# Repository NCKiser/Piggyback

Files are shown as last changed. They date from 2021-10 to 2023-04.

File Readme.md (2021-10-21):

Piggyback is a small circuit board that carries an Atmega-32u4-MU microprocessor and all of the supporting components needed for it to run. The only thing you need to provide is 5V power and ground.

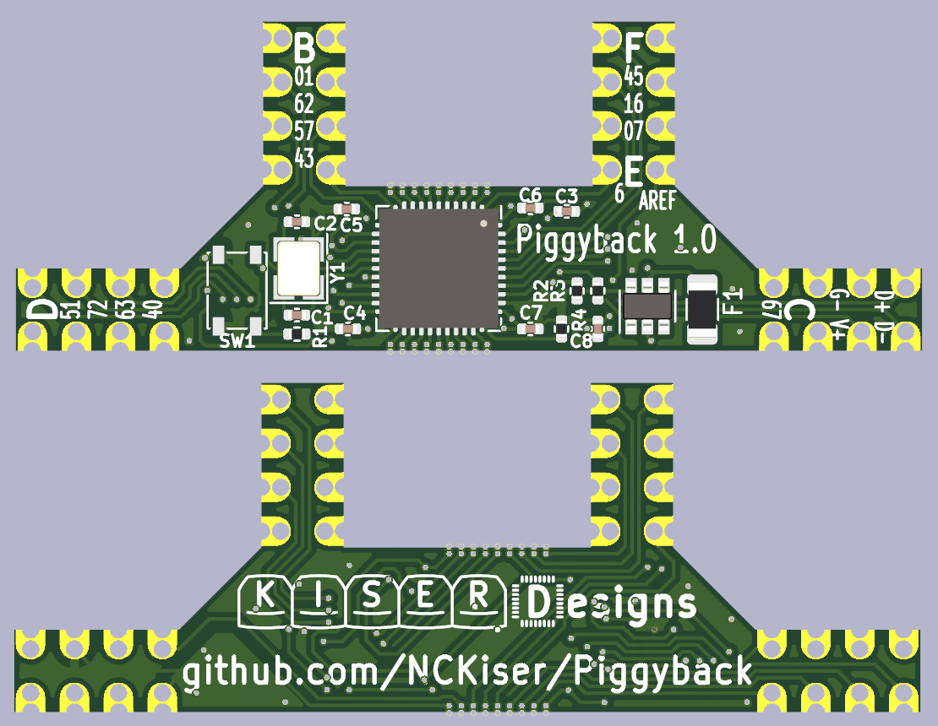
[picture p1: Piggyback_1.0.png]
Piggyback 1.0 Image


Piggyback has 4 legs, each with 8 castellated holes spaced 0.1in (2.54mm) apart. These legs break out all of the GPIO, power, and USB Data pins. Each leg roughly corresponds to a port of the 32u4's IO.

Piggyback was designed with custom mechanical keyboard PCBs in mind. The board fits snuggly under a row of MX or Alps style switches spaced 0.75in (19.05mm) apart. The legs fit within the space between the switch footprints.

Piggyback features ESD protection on the USB data lines, as well as a 500mA resettable polyfuse on the 5V line.

To use the Piggyback in your PCB designs, (load and place the symbol and footprint in your schematic and PCB), and wire it up to your USB port and key matrix. If you are using a USB-C connector, you will need to take care of the CC pins on your own (usually with 5.1k resistors to ground).

This is open-source, as long as you give credit, and is free for commercial use. You can make, modify, and sell this board as you please, as long as you do not claim to own the copyright.

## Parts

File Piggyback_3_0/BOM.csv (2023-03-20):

Designator | Footprint | Quantity | Value | LCSC Part #
C1, C2, C3, C5 | 402 | 4 | 1u | C52923
C10, C11, C12, C16, C7, C8, C9 | 402 | 7 | 100n | C1525
C4 | 402 | 1 | 10u | C15525
D1, D2, D3 | D_SOD-123 | 3 | D_Small | C81598
EZ1 | PicoEZMate-Reinforced-Lite | 1 | 78171-0004 | C2840019
F1 | 1206 | 1 | 500mA | C70076
J1, J5 | PinHeader_1x06_P2.54mm_Vertical | 2 | Conn_01x06_Female
J2 | PinHeader_1x22_P2.54mm_Vertical | 1 | Conn_01x23_Female
J3 | USB_C_Receptacle_HRO_TYPE-C-31-M-12 | 1 | USB_C_Receptacle_USB2.0 | C165948
R1, R2, R3 | 402 | 3 | 5.1k | C25905
R4, R5 | 402 | 2 | 27 | C25092
R6, R8 | 402 | 2 | 1k | C11702
R7 | 402 | 1 | -10k
SW7, SW8, SW9 | SW_MX_1u | 3 | MX_SW_solder
SWR1, SWR2 | SW_Push_SPST_NO_Alps_SKRK | 2 | SW_SPST | C843669
U1 | QFN40P700X700X90-57N | 1 | RP2040TR7 | C2040
U2 | SOT-23 | 1 | XC6206PxxxMR | C5446
U3 | SOT-23-6-routable | 1 | SRV05-4 | C85364
U4 | SOIC-8_5.23x5.23mm_P1.27mm | 1 | W25Q128JVS | C97521
Y2 | Resonator_SMD_Murata_CSTxExxV-3Pin_3.0x1.1mm | 1 | Crystal_GND2_Small | C2659460

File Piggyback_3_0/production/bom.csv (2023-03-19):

Designator | Footprint | Quantity | Value | LCSC Part #
C1, C2, C3, C5 | 0402 | 4 | 1u
C10, C11, C12, C16, C7, C8, C9 | 0402 | 7 | 100n
C4 | 0402 | 1 | 10u
D1, D2, D3 | D_SOD-123 | 3 | D_Small
EZ1 | PicoEZMate-Reinforced-Lite | 1 | 78171-0004
F1 | 1206 | 1 | 500mA
J1, J5 | PinHeader_1x06_P2.54mm_Vertical | 2 | Conn_01x06_Female
J2 | PinHeader_1x22_P2.54mm_Vertical | 1 | Conn_01x23_Female
J3 | USB_C_Receptacle_HRO_TYPE-C-31-M-12 | 1 | USB_C_Receptacle_USB2.0
R1, R2, R3 | 0402 | 3 | 5.1k
R4, R5 | 0402 | 2 | 27
R6, R8 | 0402 | 2 | 1k
R7 | 0402 | 1 | -10k
SW7, SW8, SW9 | SW_MX_1u | 3 | MX_SW_solder
SWR1, SWR2 | SW_Push_SPST_NO_Alps_SKRK | 2 | SW_SPST
U1 | QFN40P700X700X90-57N | 1 | RP2040TR7
U2 | SOT-23 | 1 | XC6206PxxxMR
U3 | SOT-23-6-routable | 1 | SRV05-4
U4 | SOIC-8_5.23x5.23mm_P1.27mm | 1 | W25Q128JVS
Y2 | Resonator_SMD_Murata_CSTxExxV-3Pin_3.0x1.1mm | 1 | Crystal_GND2_Small

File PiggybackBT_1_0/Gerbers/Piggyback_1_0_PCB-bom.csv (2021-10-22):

Designator | Footprint | Value | Tolerance | MFG Part # | Can replace with other similar parts?
Y1 | Y_2520-4Pin_2.5x2.0mm | 16MHz |  | 7E16000E09UCG | Maybe
C8 | C_0402_1005Metric | 10uF | 10% | GRM155R61A106ME44D | Yes
C1,C2 | C_0402_1005Metric | 22pF | 10% | 0402CG220J500NT | Yes
C4,C5,C6,C7 | C_0402_1005Metric | 0.1uF | 10% | CL05B104KO5NNNC | Yes
C3 | C_0402_1005Metric | 1uF | 10% | CL05A105KA5NQNC | Yes
R1,R4 | R_0402_1005Metric | 10k | 10% | 0402WGF1002TCE | Yes
SW1 | SW_SPST_PTS810 |  |  | PTS810SJM250SMTRLFS | No
F1 | F_1206_3216Metric | 500mA |  | nSMD050-24V | No
R3,R2 | R_0402_1005Metric | 22 ohm | 10% | 0402WGF220JTCE | Yes
U1 | SOT-23-6 |  |  | SRV05-4-P-T7 | No
U2 | QFN-44-1EP_7x7mm_P0.5mm_EP5.2x5.2mm | Atmel-DFU Bootloader |  | ATmega32U4-MU | No

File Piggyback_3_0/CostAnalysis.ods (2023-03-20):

Quantity | Board | Assembly | Total | per Unit | Shipping | Total | total per unit
5 | 4.53 | 71.94 | 76.47 | 15.294 | 20 | 96.47 | 19.294
10 | 5.53 | 84.18 | 89.71 | 8.971 | 20 | 109.71 | 10.971
15 | 10.53 | 98.28 | 108.81 | 7.254 | 20 | 128.81 | 8.58733333333333
20 | 12.53 | 112.39 | 124.92 | 6.246 | 21 | 145.92 | 7.296
25 | 14.53 | 125.97 | 140.5 | 5.62 | 21 | 161.5 | 6.46
30 | 16.53 | 133.74 | 150.27 | 5.009 | 30 | 180.27 | 6.009
5 | 4.53 | 44.67 | 49.2 | 9.84 | 20 | 69.2 | 13.84
10 | 5.53 | 57.02 | 62.55 | 6.255 | 20 | 82.55 | 8.255
15 | 6.53 | 71.16 | 77.69 | 5.17933333333333 | 20 | 97.69 | 6.51266666666667
20 | 7.23 | 85.3 | 92.53 | 4.6265 | 21 | 113.53 | 5.6765
25 | 7.93 | 98.86 | 106.79 | 4.2716 | 21 | 127.79 | 5.1116
30 | 8.63 | 106.58 | 115.21 | 3.84033333333333 | 21 | 136.21 | 4.54033333333333

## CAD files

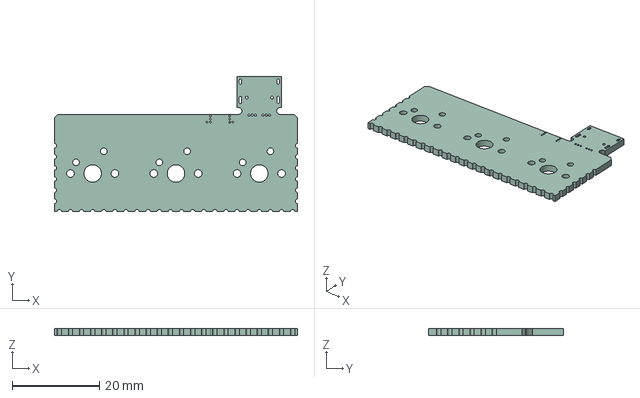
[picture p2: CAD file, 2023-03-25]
Piggyback_3_0/Piggyback_3_0.step
55.6 x 31.0 x 1.58 mm

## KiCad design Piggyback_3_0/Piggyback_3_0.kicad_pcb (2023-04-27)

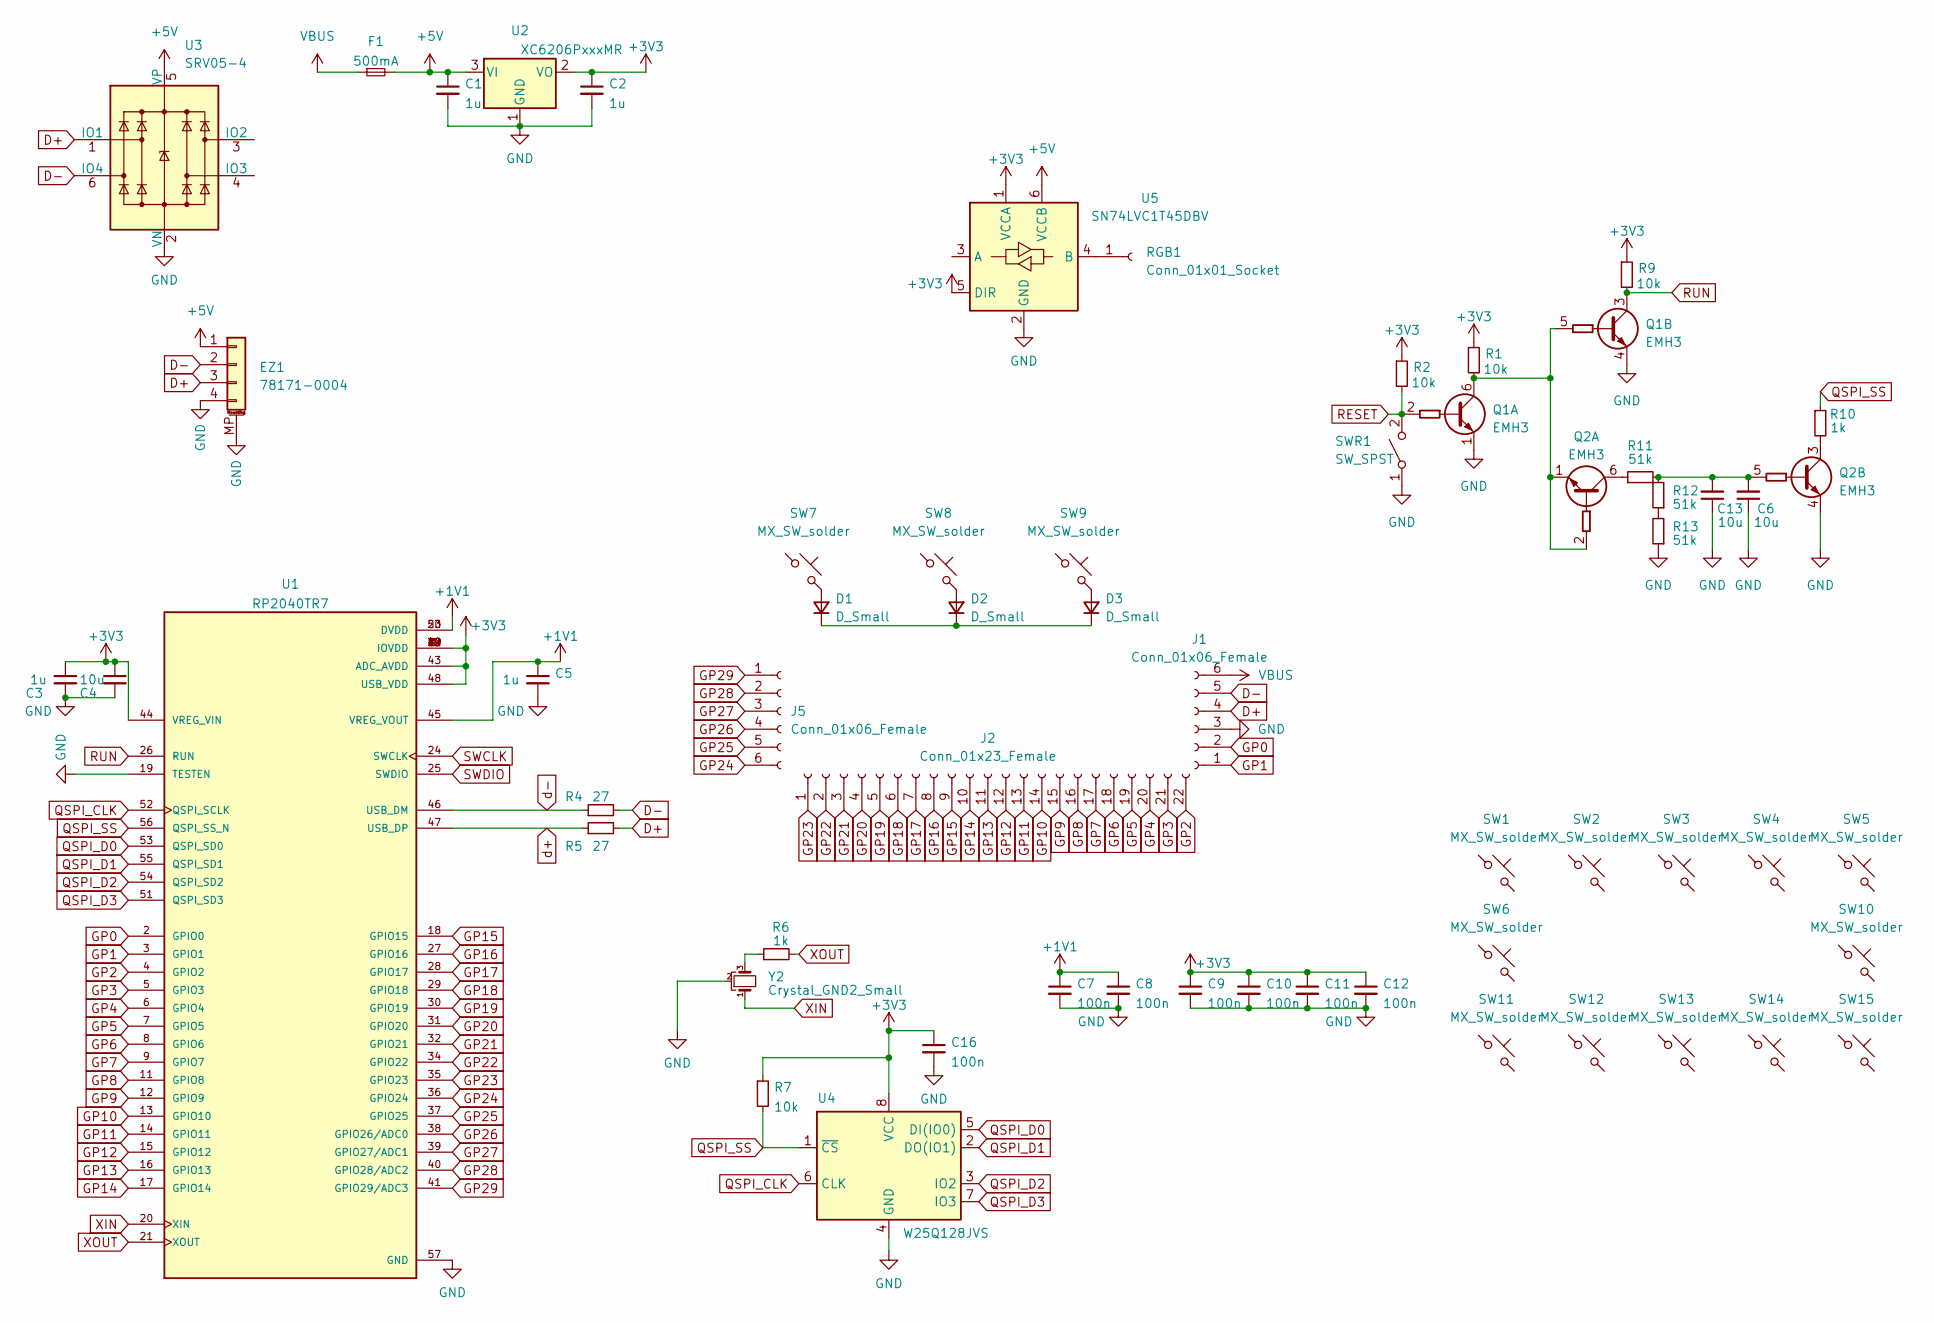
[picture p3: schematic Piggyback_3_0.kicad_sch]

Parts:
C1, C2, C3, C5: 1u; C_0402_1005Metric
C4, C6, C13: 10u; C_0402_1005Metric
C7, C8, C9, C10, C11, C12, C16: 100n; C_0402_1005Metric
D1, D2, D3: D_Small; D_SOD-123
EZ1: 78171-0004; PicoEZMate-Reinforced-Lite; Manufacturer Part Number 78171-0004; LCSC Part Number C588524
F1: 500mA; Fuse_1206_3216Metric
J1, J5: Conn_01x06_Female; PinHeader_1x06_P2.54mm_Vertical
J2: Conn_01x23_Female; PinHeader_1x22_P2.54mm_Vertical
Q1, Q2: EMH3; SOT-563
R1, R2, R7, R9: 10k; R_0402_1005Metric
R4, R5: 27; R_0402_1005Metric
R6, R10: 1k; R_0402_1005Metric
R11, R12, R13: 51k; R_0402_1005Metric
RGB1: Conn_01x01_Socket; PinSocket_1x01_P2.54mm_Vertical
SW1, SW2, SW3, SW4, SW5, SW6, SW7, SW8, SW9, SW10, SW11, SW12, SW13, SW14, SW15: MX_SW_solder; SW_MX_1u
SWR1: SW_SPST; SW_Push_SPST_NO_Alps_SKRK
U1: RP2040TR7; QFN40P700X700X90-57N; PARTREV 1.7.1
U2: XC6206PxxxMR; SOT-23
U3: SRV05-4; SOT-23-6-routable
U4: W25Q128JVS; SOIC-8_5.23x5.23mm_P1.27mm
U5: SN74LVC1T45DBV; SOT-23-6
Y2: Crystal_GND2_Small; Resonator_SMD_Murata_CSTxExxV-3Pin_3.0x1.1mm

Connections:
+1V1: C5.1, C7.1, C8.1, U1.23 (DVDD), U1.45 (VREG_VOUT), U1.50 (DVDD)
+3V3: C2.1, C3.1, C4.1, C9.1, C10.1, C11.1, C12.1, C16.1, R1.1, R2.1, R7.1, R9.1, U1.1 (IOVDD), U1.10 (IOVDD), U1.22 (IOVDD), U1.33 (IOVDD), U1.42 (IOVDD), U1.43 (ADC_AVDD), U1.44 (VREG_VIN), U1.48 (USB_VDD), U1.49 (IOVDD), U2.2 (VO), U4.8 (VCC), U5.1 (VCCA), U5.5 (DIR)
+5V: C1.1, EZ1.1, F1.2, U2.3 (VI), U3.5 (VP), U5.6 (VCCB)
D+: EZ1.3, J1.4, R5.2, U3.1 (IO1)
D-: EZ1.2, J1.5, R4.2, U3.6 (IO4)
GND: C1.2, C2.2, C3.2, C4.2, C5.2, C6.1, C7.2, C8.2, C9.2, C10.2, C11.2, C12.2, C13.1, C16.2, EZ1.4, EZ1.MP (MountPin), J1.3, Q1.1 (E1), Q1.4 (E2), Q2.4 (E2), R13.1, SWR1.1 (A), U1.19 (TESTEN), U1.57 (GND), U2.1 (GND), U3.2 (VN), U4.4 (GND), U5.2 (GND), Y2.2
GP0: J1.2, U1.2 (GPIO0)
GP1: J1.1, U1.3 (GPIO1)
GP2: J2.22, U1.4 (GPIO2)
GP3: J2.21, U1.5 (GPIO3)
GP4: J2.20, U1.6 (GPIO4)
GP5: J2.19, U1.7 (GPIO5)
GP6: J2.18, U1.8 (GPIO6)
GP7: J2.17, U1.9 (GPIO7)
GP8: J2.16, U1.11 (GPIO8)
GP9: J2.15, U1.12 (GPIO9)
GP10: J2.14, U1.13 (GPIO10)
GP11: J2.13, U1.14 (GPIO11)
GP12: J2.12, U1.15 (GPIO12)
GP13: J2.11, U1.16 (GPIO13)
GP14: J2.10, U1.17 (GPIO14)
GP15: J2.9, U1.18 (GPIO15)
GP16: J2.8, U1.27 (GPIO16)
GP17: J2.7, U1.28 (GPIO17)
GP18: J2.6, U1.29 (GPIO18)
GP19: J2.5, U1.30 (GPIO19)
GP20: J2.4, U1.31 (GPIO20)
GP21: J2.3, U1.32 (GPIO21)
GP22: J2.2, U1.34 (GPIO22)
GP23: J2.1, U1.35 (GPIO23)
GP24: J5.6, U1.36 (GPIO24)
GP25: J5.5, U1.37 (GPIO25)
GP26: J5.4, U1.38 (GPIO26/ADC0)
GP27: J5.3, U1.39 (GPIO27/ADC1)
GP28: J5.2, U1.40 (GPIO28/ADC2)
GP29: J5.1, U1.41 (GPIO29/ADC3)
unnamed: D1.2 (A), SW7.2
unnamed: D1.1 (K), D2.1 (K), D3.1 (K)
unnamed: D2.2 (A), SW8.2
unnamed: D3.2 (A), SW9.2
unnamed: Q1.5 (B2), Q1.6 (C1), Q2.1 (E1), Q2.2 (B1), R1.2
unnamed: Q2.6 (C1), R11.1
unnamed: C6.2, C13.2, Q2.5 (B2), R11.2, R12.2
unnamed: Q2.3 (C2), R10.2
unnamed: R6.1, Y2.3
unnamed: R12.1, R13.2
unnamed: RGB1.1, U5.4 (B)
QSPI_CLK: U1.52 (QSPI_SCLK), U4.6 (CLK)
QSPI_D0: U1.53 (QSPI_SD0), U4.5 (DI(IO0))
QSPI_D1: U1.55 (QSPI_SD1), U4.2 (DO(IO1))
QSPI_D2: U1.54 (QSPI_SD2), U4.3 (IO2)
QSPI_D3: U1.51 (QSPI_SD3), U4.7 (IO3)
QSPI_SS: R7.2, R10.1, U1.56 (QSPI_SS_N), U4.1 (~CS)
RESET: Q1.2 (B1), R2.2, SWR1.2 (B)
RUN: Q1.3 (C2), R9.2, U1.26 (RUN)
SWCLK: U1.24 (SWCLK)
SWDIO: U1.25 (SWDIO)
VBUS: F1.1, J1.6
XIN: U1.20 (XIN), Y2.1
XOUT: R6.2, U1.21 (XOUT)
d+: R5.1, U1.47 (USB_DP)
d-: R4.1, U1.46 (USB_DM)

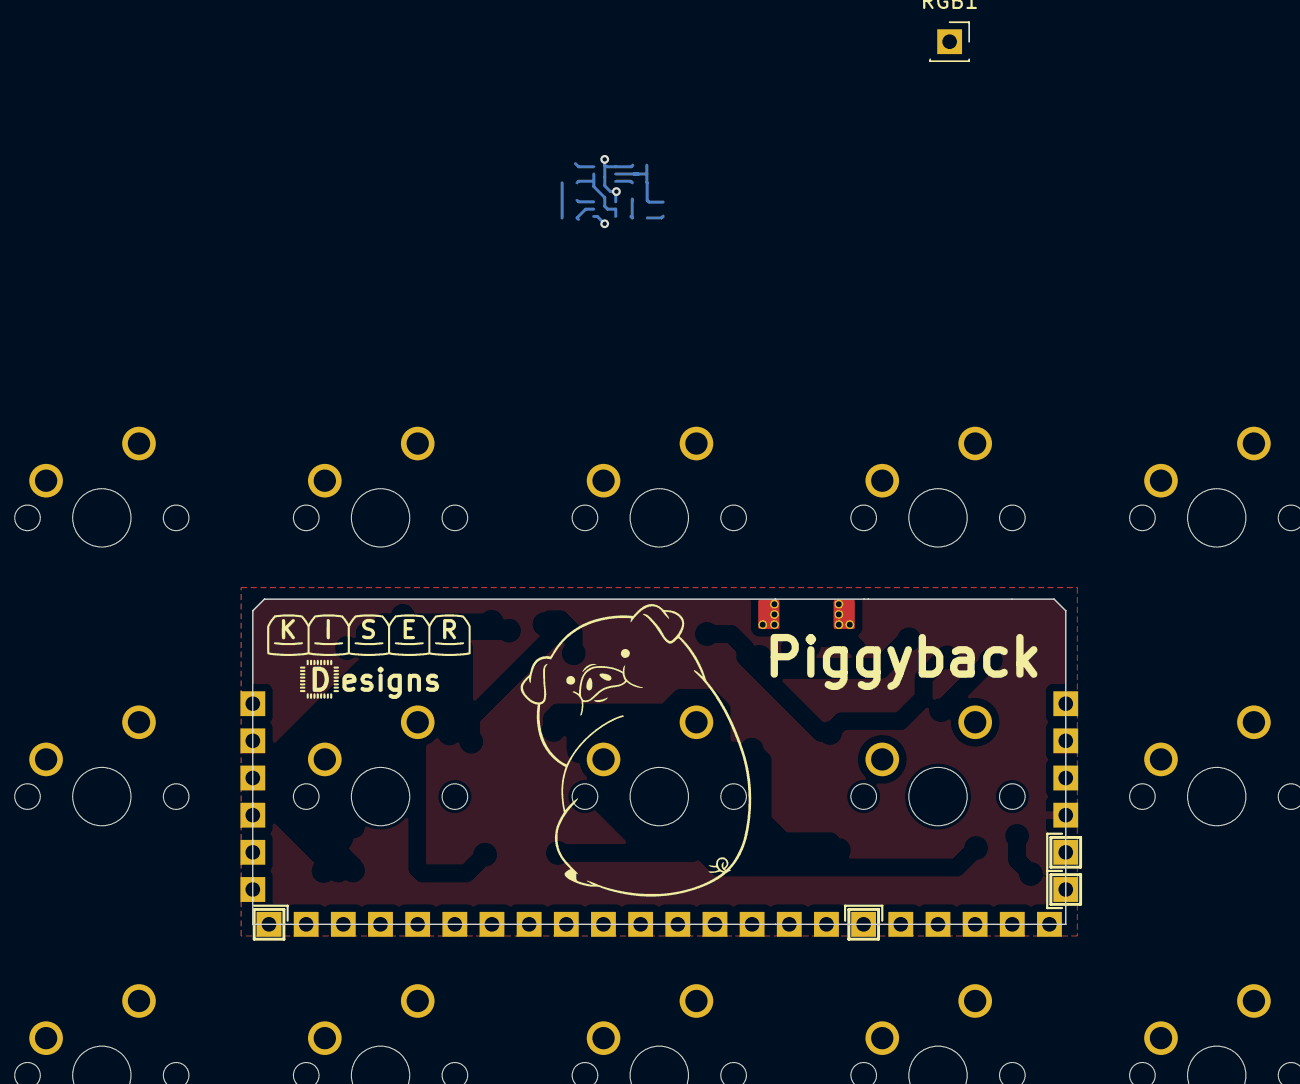
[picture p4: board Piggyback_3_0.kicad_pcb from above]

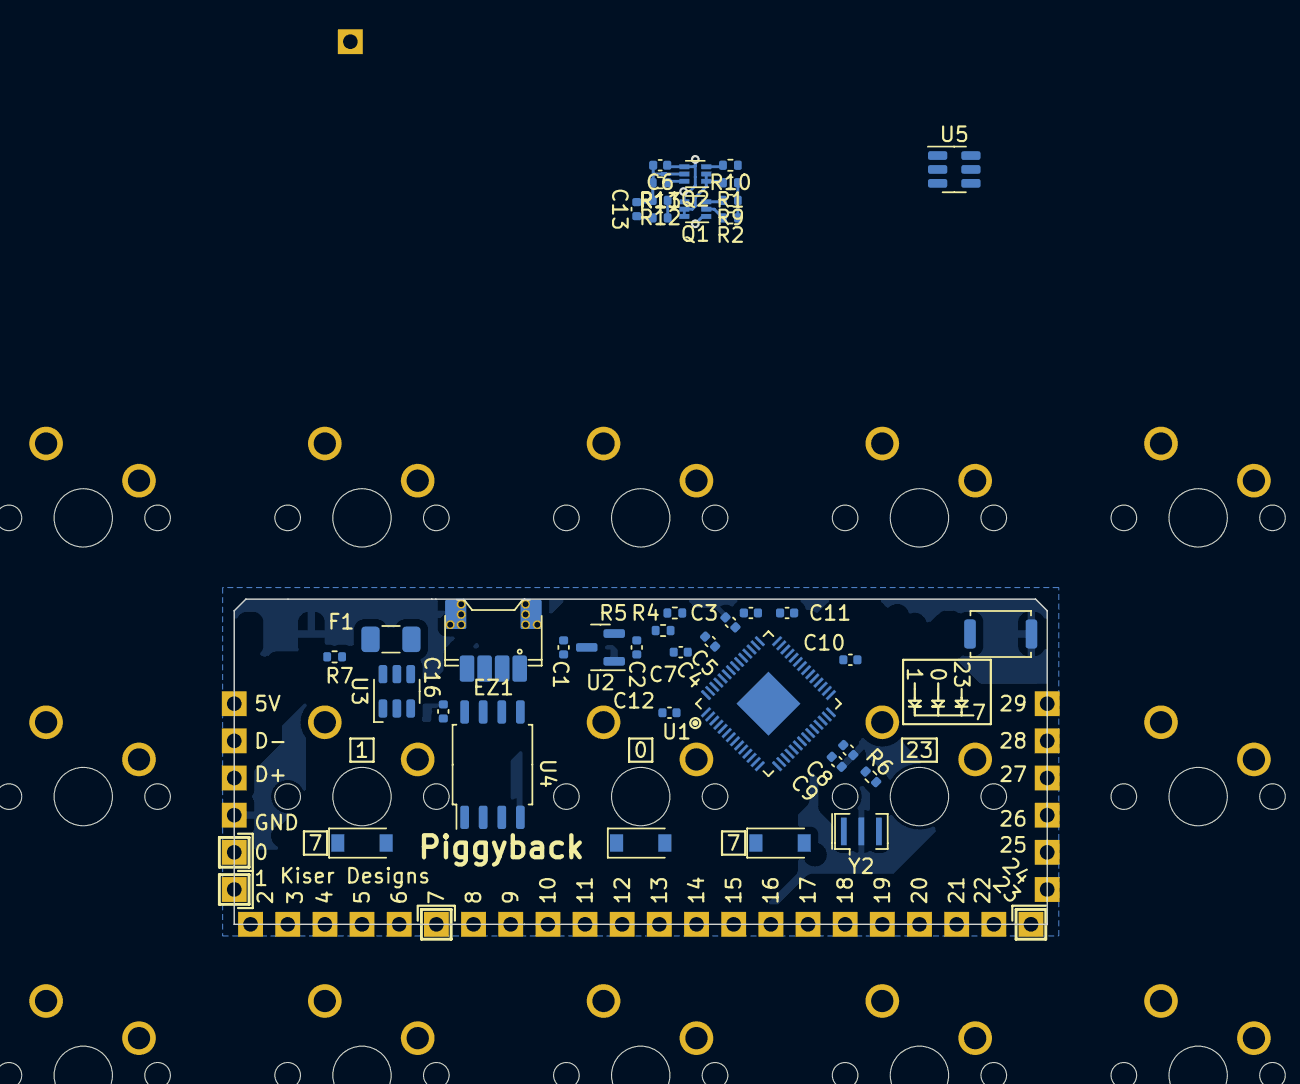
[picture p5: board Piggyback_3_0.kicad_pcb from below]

Board: 2 copper layers, 55.6 x 22.2 mm, 58 parts (40 on the bottom side), 60 nets.

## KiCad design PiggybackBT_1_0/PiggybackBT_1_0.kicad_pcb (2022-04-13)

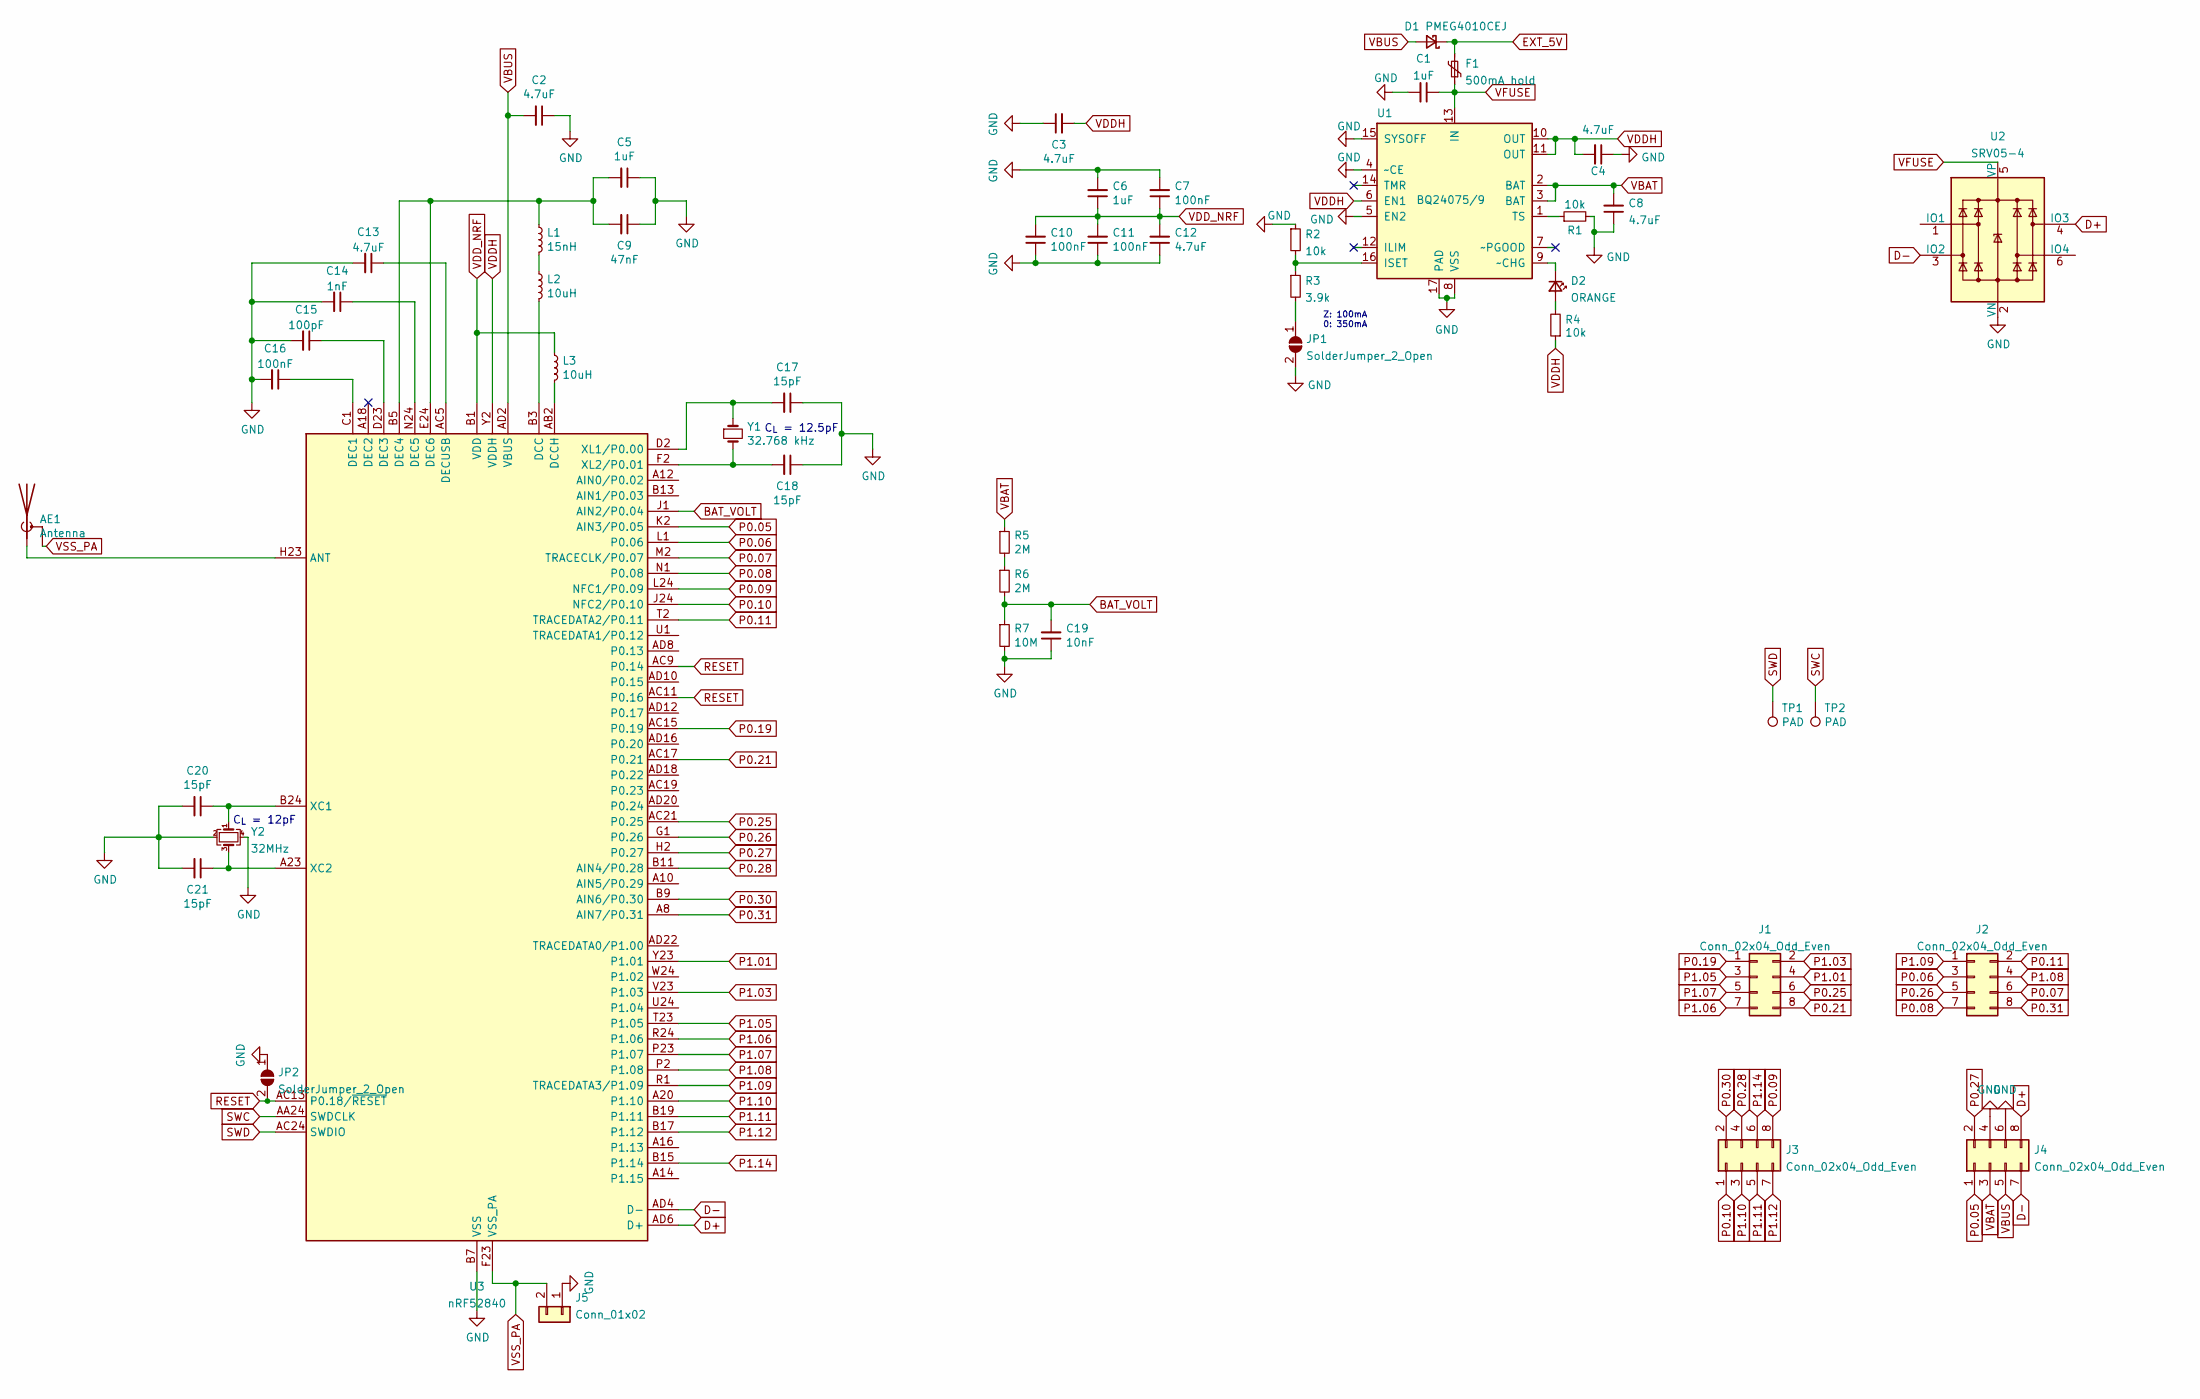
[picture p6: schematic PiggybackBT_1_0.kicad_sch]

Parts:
AE1: Antenna; U.FL_Hirose_U.FL-R-SMT-1_Vertical
C1, C5, C6: 1uF; C_0402_1005Metric; Manufacturer Part CL05A105KO5NNNC; LCSC Part C52923
C2, C3, C4, C8, C12, C13: 4.7uF; C_0402_1005Metric; Manufacturer Part CL05A475KP5NRNC; LCSC Part C368809
C7, C10, C11, C16: 100nF; C_0402_1005Metric; Manufacturer Part CL05B104KA5NNNC; LCSC Part C1525
C9: 47nF; C_0402_1005Metric; Manufacturer Part CL05B473KO5NNNC; LCSC Part C307434
C14: 1nF; C_0402_1005Metric; Manufacturer Part CL05B102KB5NNNC; LCSC Part C14442
C15: 100pF; C_0402_1005Metric; Manufacturer Part CL05C101JB5NNNC; LCSC Part C26409
C17, C18, C20, C21: 15pF; C_0402_1005Metric; Manufacturer Part CL05C150JB51PNC; LCSC Part C307341
C19: 10nF; C_0402_1005Metric; Manufacturer Part CL05B103KB5NNNC; LCSC Part C15195
D1: PMEG4010CEJ; D_SOD-323F; Manufacturer Part PMEG4010CEJ; LCSC Part C50704
D2: ORANGE; LED_0603_1608Metric; Manufacturer Part 19-217/S2C-AQ1R1B/3T; LCSC Part C160478
F1: 500mA hold; Fuse_0402_1005Metric; Manufacturer Part 0402L050SLKR; LCSC Part C206938
J1, J2, J3, J4: Conn_02x04_Odd_Even; PinHeader_2x04_P2.54mm_Vertical
J5: Conn_01x02; NetTie-2_SMD_Pad0.5mm
JP1, JP2: SolderJumper_2_Open; SolderJumper-2_P1.3mm_Open_RoundedPad1.0x1.5mm
L1: 15nH; L_0402_1005Metric; Manufacturer Part MLG1005S15NJT000; LCSC Part C76763
L2, L3: 10uH; L_0603_1608Metric; Manufacturer Part MLF1608E100KTD00; LCSC Part C76732
R1, R2, R4: 10k; R_0402_1005Metric; Manufacturer Part RC0402FR-0710KL; LCSC Part C60490
R3: 3.9k; R_0402_1005Metric; Manufacturer Part RC0402FR-073K9L; LCSC Part C131467
R5, R6: 2M; R_0402_1005Metric; Manufacturer Part RC0402FR-072ML; LCSC Part C138014
R7: 10M; R_0402_1005Metric; Manufacturer Part RC0402FR-0710ML; LCSC Part C138067
TP1, TP2: PAD; TestPoint_Pad_D1.0mm
U1: BQ24075/9; VQFN-16-1EP_3x3mm_P0.5mm_EP1.6x1.6mm; Manufacturer Part BQ24075RGTR; LCSC Part C15464
U2: SRV05-4; SOT-23-6
U3: nRF52840; Nordic_AQFN-73-1EP_7x7mm_P0.5mm
Y1: 32.768 kHz; Crystal_SMD_2012-2Pin_2.0x1.2mm; Manufacturer Part SC20S-12.5PF20PPM; LCSC Part C97607
Y2: 32MHz; Crystal_SMD_2016-4Pin_2.0x1.6mm; Manufacturer Part Q22FA1280001800; LCSC Part C255896

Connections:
BAT_VOLT: C19.2, R6.2, R7.1, U3.J1 (AIN2/P0.04)
D+: J4.8, U2.4 (IO3), U3.AD6 (D+)
D-: J4.7, U2.3 (IO2), U3.AD4 (D-)
EXT_5V: D1.1 (K), F1.2
GND: C1.2, C2.1, C3.1, C4.1, C5.1, C6.2, C7.2, C8.1, C9.1, C10.1, C11.1, C12.1, C13.2, C14.2, C15.2, C16.2, C17.1, C18.1, C19.1, C20.2, C21.2, J4.4, J4.6, J5.1, JP1.2 (B), JP2.1 (A), R1.2, R2.1, R7.2, U1.4 (~CE), U1.5 (EN2), U1.8 (VSS), U1.15 (SYSOFF), U1.17 (PAD), U2.2 (VN), U3.B7 (VSS), U3.EP (VSS), Y2.2, Y2.4
unnamed: AE1.1 (A), U3.H23 (ANT)
unnamed: C5.2, C9.2, L1.1, U3.B5 (DEC4), U3.E24 (DEC6)
unnamed: C13.1, U3.AC5 (DECUSB)
unnamed: C14.1, U3.N24 (DEC5)
unnamed: C15.1, U3.D23 (DEC3)
unnamed: C16.1, U3.C1 (DEC1)
unnamed: C17.2, U3.D2 (XL1/P0.00), Y1.1
unnamed: C18.2, U3.F2 (XL2/P0.01), Y1.2
unnamed: C20.1, U3.B24 (XC1), Y2.1
unnamed: C21.1, U3.A23 (XC2), Y2.3
unnamed: D2.1 (K), U1.9 (~CHG)
unnamed: D2.2 (A), R4.2
unnamed: JP1.1 (A), R3.2
unnamed: L1.2, L2.1
unnamed: L2.2, U3.B3 (DCC)
unnamed: L3.2, U3.AB2 (DCCH)
unnamed: R1.1, U1.1 (TS)
unnamed: R2.2, R3.1, U1.16 (ISET)
unnamed: R5.2, R6.1
P0.05: J4.1, U3.K2 (AIN3/P0.05)
P0.06: J2.3, U3.L1 (P0.06)
P0.07: J2.6, U3.M2 (TRACECLK/P0.07)
P0.08: J2.7, U3.N1 (P0.08)
P0.09: J3.8, U3.L24 (NFC1/P0.09)
P0.10: J3.1, U3.J24 (NFC2/P0.10)
P0.11: J2.2, U3.T2 (TRACEDATA2/P0.11)
P0.19: J1.1, U3.AC15 (P0.19)
P0.21: J1.8, U3.AC17 (P0.21)
P0.25: J1.6, U3.AC21 (P0.25)
P0.26: J2.5, U3.G1 (P0.26)
P0.27: J4.2, U3.H2 (P0.27)
P0.28: J3.4, U3.B11 (AIN4/P0.28)
P0.30: J3.2, U3.B9 (AIN6/P0.30)
P0.31: J2.8, U3.A8 (AIN7/P0.31)
P1.01: J1.4, U3.Y23 (P1.01)
P1.03: J1.2, U3.V23 (P1.03)
P1.05: J1.3, U3.T23 (P1.05)
P1.06: J1.7, U3.R24 (P1.06)
P1.07: J1.5, U3.P23 (P1.07)
P1.08: J2.4, U3.P2 (P1.08)
P1.09: J2.1, U3.R1 (TRACEDATA3/P1.09)
P1.10: J3.3, U3.A20 (P1.10)
P1.11: J3.5, U3.B19 (P1.11)
P1.12: J3.7, U3.B17 (P1.12)
P1.14: J3.6, U3.B15 (P1.14)
RESET: JP2.2 (B), U3.AC9 (P0.14), U3.AC11 (P0.16), U3.AC13 (P0.18/~RESET)
SWC: TP2.1, U3.AA24 (SWDCLK)
SWD: TP1.1, U3.AC24 (SWDIO)
VBAT: C8.2, J4.3, R5.1, U1.2 (BAT), U1.3 (BAT)
VBUS: C2.2, D1.2 (A), J4.5, U3.AD2 (VBUS)
VDDH: C3.2, C4.2, R4.1, U1.6 (EN1), U1.10 (OUT), U1.11 (OUT), U3.Y2 (VDDH)
VDD_NRF: C6.1, C7.1, C10.2, C11.2, C12.2, L3.1, U3.A22 (VDD), U3.AD14 (VDD), U3.AD23 (VDD), U3.B1 (VDD), U3.W1 (VDD)
VFUSE: C1.1, F1.1, U1.13 (IN), U2.5 (VP)
VSS_PA: AE1.2 (Shield), J5.2, U3.F23 (VSS_PA)

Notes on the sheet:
C_{L} = 12pF
C_{L} = 12.5pF
Z: 100mA 0: 350mA

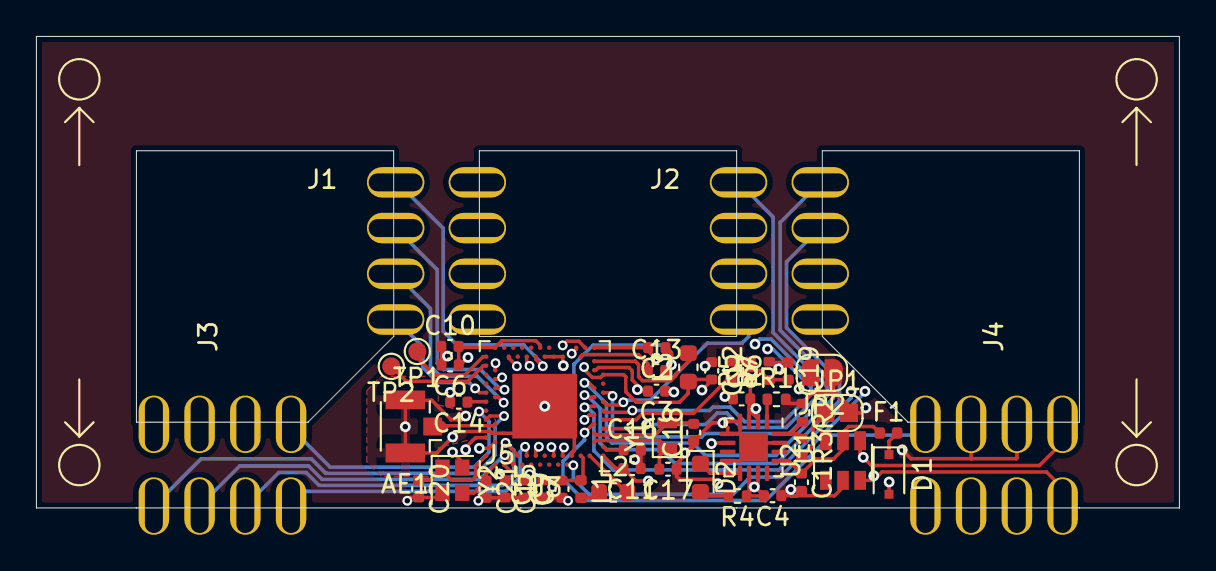
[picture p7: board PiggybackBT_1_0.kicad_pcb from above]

Board: 4 copper layers, 63.5 x 26.2 mm, 49 parts (0 on the bottom side), 59 nets.

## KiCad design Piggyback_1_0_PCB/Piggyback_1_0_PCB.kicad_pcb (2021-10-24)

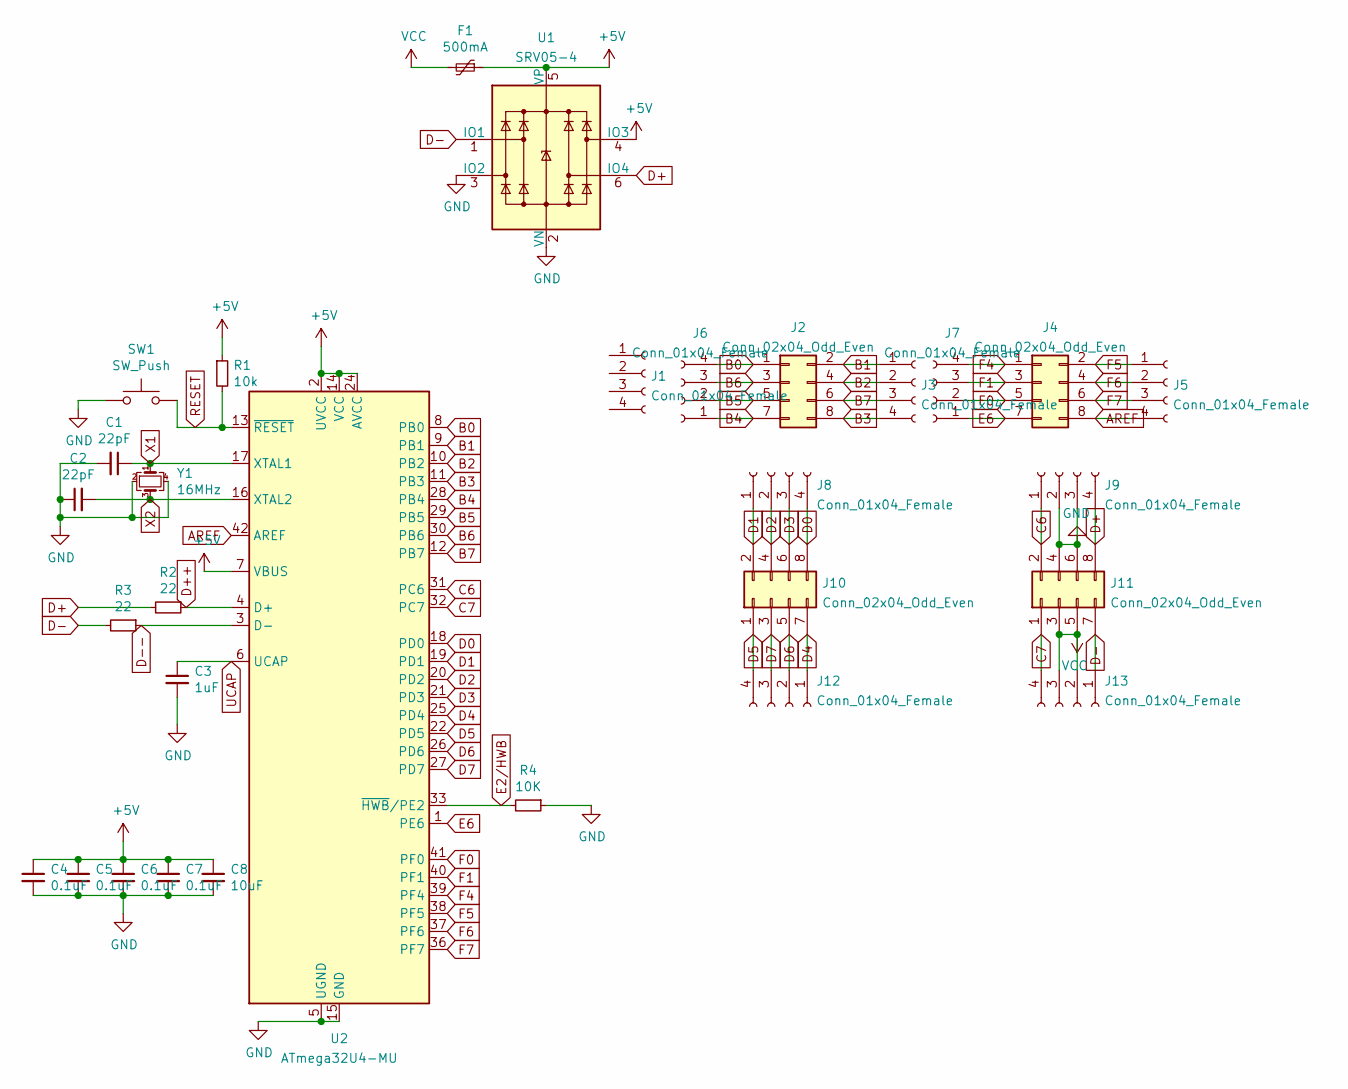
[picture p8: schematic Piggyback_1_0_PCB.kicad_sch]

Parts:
C1, C2: 22pF; C_0402_1005Metric
C3: 1uF; C_0402_1005Metric
C4, C5, C6, C7: 0.1uF; C_0402_1005Metric
C8: 10uF; C_0402_1005Metric
F1: 500mA; Fuse_1206_3216Metric
J1: Conn_01x04_Female
J2, J4, J10, J11: Conn_02x04_Odd_Even; PinHeader_2x04_P2.54mm_Vertical
J3, J5, J6, J7, J8, J9, J12, J13: Conn_01x04_Female; PinHeader_1x04_P2.54mm_Vertical
R1: 10k; R_0402_1005Metric
R2, R3: 22; R_0402_1005Metric
R4: 10K; R_0402_1005Metric
SW1: SW_Push; SW_SPST_PTS810
U1: SRV05-4; SOT-23-6
U2: ATmega32U4-MU; QFN-44-1EP_7x7mm_P0.5mm_EP5.2x5.2mm
Y1: 16MHz; Crystal_SMD_2520-4Pin_2.5x2.0mm

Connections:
+5V: C4.1, C5.1, C6.1, C7.1, C8.1, F1.1, R1.1, U1.4 (IO3), U1.5 (VP), U2.2 (UVCC), U2.7 (VBUS), U2.14 (VCC), U2.24 (AVCC), U2.34 (VCC), U2.44 (AVCC)
AREF: J4.8, J5.4, U2.42 (AREF)
B0: J2.1, J6.4, U2.8 (PB0)
B1: J2.2, J3.1, U2.9 (PB1)
B2: J2.4, J3.2, U2.10 (PB2)
B3: J2.8, J3.4, U2.11 (PB3)
B4: J2.7, J6.1, U2.28 (PB4)
B5: J2.5, J6.2, U2.29 (PB5)
B6: J2.3, J6.3, U2.30 (PB6)
B7: J2.6, J3.3, U2.12 (PB7)
C6: J9.1, J11.2, U2.31 (PC6)
C7: J11.1, J13.4, U2.32 (PC7)
D0: J8.4, J10.8, U2.18 (PD0)
D1: J8.1, J10.2, U2.19 (PD1)
D2: J8.2, J10.4, U2.20 (PD2)
D3: J8.3, J10.6, U2.21 (PD3)
D4: J10.7, J12.1, U2.25 (PD4)
D5: J10.1, J12.4, U2.22 (PD5)
D6: J10.5, J12.2, U2.26 (PD6)
D7: J10.3, J12.3, U2.27 (PD7)
D+: J9.4, J11.8, R2.2, U1.6 (IO4)
D++: R2.1, U2.4 (D+)
D-: J11.7, J13.1, R3.2, U1.1 (IO1)
D--: R3.1, U2.3 (D-)
E2/HWB: R4.2, U2.33 (~HWB/PE2)
E6: J4.7, J7.1, U2.1 (PE6)
F0: J4.5, J7.2, U2.41 (PF0)
F1: J4.3, J7.3, U2.40 (PF1)
F4: J4.1, J7.4, U2.39 (PF4)
F5: J4.2, J5.1, U2.38 (PF5)
F6: J4.4, J5.2, U2.37 (PF6)
F7: J4.6, J5.3, U2.36 (PF7)
GND: C1.2, C2.1, C3.2, C4.2, C5.2, C6.2, C7.2, C8.2, J9.2, J9.3, J11.4, J11.6, R4.1, SW1.1, U1.2 (VN), U1.3 (IO2), U2.5 (UGND), U2.15 (GND), U2.23 (GND), U2.35 (GND), U2.43 (GND), U2.45 (GND), Y1.2, Y1.4
RESET: R1.2, SW1.2, U2.13 (~RESET)
UCAP: C3.1, U2.6 (UCAP)
VCC: F1.2, J11.3, J11.5, J13.2, J13.3
X1: C1.1, U2.17 (XTAL1), Y1.1
X2: C2.2, U2.16 (XTAL2), Y1.3

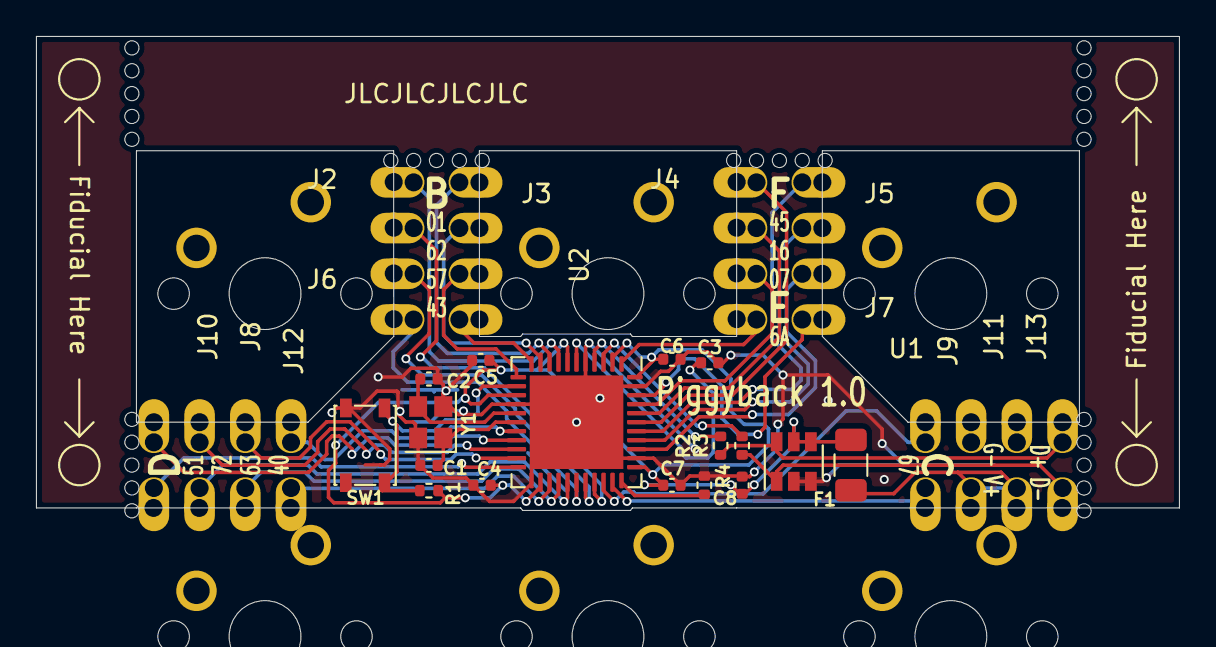
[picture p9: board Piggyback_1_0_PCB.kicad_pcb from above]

Board: 2 copper layers, 63.5 x 26.3 mm, 29 parts (0 on the bottom side), 38 nets.

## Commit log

2021-10-21 1.0 commit
    [Piggyback_1_0_PCB.kicad_pcb, Piggyback_1_0_PCB.kicad_sch, Piggyback_1_0_PCB.sch]
2021-10-21 Public commit
    [Piggyback_1_0_PCB.kicad_pcb]
2021-10-21 Connected NC pads to GND and 5V
    [Piggyback_1_0_PCB.kicad_pcb, Piggyback_1_0_PCB.kicad_sch]
2021-10-21 More material around edge vias, no longer "castellated"
    [Piggyback_1_0_PCB.kicad_pcb]
2021-10-21 loose ends
    [Piggyback_1_0_PCB.kicad_pcb]
2021-10-21 reset button clearance
    [Piggyback_1_0_PCB.kicad_pcb]
2021-10-21 smaller crystal
    [Piggyback_1_0_PCB.kicad_pcb]
2021-10-22 Changes for FAB
    [Piggyback_1_0_PCB-B_Cu.gbl, Piggyback_1_0_PCB-B_Mask.gbs, Piggyback_1_0_PCB-B_Paste.gbp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]
2021-10-24 created KiCad symbol and footprints for 1.0
    [Piggyback_1_0_PCB.kicad_pcb]
2021-10-31 Manu for 43u5 version, added BT variant
    [PiggybackBT_1_0-B_Cu.gbl, PiggybackBT_1_0-B_Mask.gbs, PiggybackBT_1_0-B_Paste.gbp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]
2022-04-13 Minor Updates
    [PiggybackBT_1_0.kicad_pcb, PiggybackBT_1_0.kicad_sch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]
2023-03-15 made a lot of changes
    [Piggyback_2_0.kicad_pcb]
2023-03-18 add gerbers
    [Piggyback_2_0-B_Cu.gbr, Piggyback_2_0-B_Mask.gbr, Piggyback_2_0-B_Paste.gbr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]
2023-03-19 cost engineering
    [BOM.csv, CostAnalysis.ods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]
2023-03-19 further cost reductions
    [BOM.csv, Piggyback_2_0.kicad_pcb, Piggyback_2_0.kicad_sch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]
2023-03-20 usb-spec crystal
    [BOM.csv, CostAnalysis.ods, Piggyback_2_0.kicad_pcb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]
2023-03-25 add 3d model, and footprint
    [Piggyback_2_0.step]
2023-04-07 add untested footprint .zip
    [Piggyback_2_0.step]
2023-04-27 add piggyback 3
    [BOM.csv, CostAnalysis.ods, Piggyback_2_0.kicad_sch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]
